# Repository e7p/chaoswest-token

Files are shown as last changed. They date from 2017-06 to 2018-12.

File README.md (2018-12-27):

## Welcome

This is the official documentation of the Chaos-West Token which is given to anyone on the SHA2017 camp and also on the 35C3 who supports us with a reasonable donation for us (mainly to be able to split-up costs we all belonging to Chaos-West share on the event). If you really want to have one of these wonderful and token kits, just come to our Chaos-West info desk on the event and support us with a recommended donation. In case there are some left-overs after the event, it should be somehow possible to receive these if you still want to get a token after the event. The easiest would probably be to write an e-mail to cwtkn@devtal.de which should address the makers of this token. As this is a project released to the public domain, consolidating the thought of open hardware and free software, you can also produce the board by yourself (or wire up the rather simple circuit on a breadboard), but getting it from us really supports the collective activities of Chaos-West, just consider that.

## Quick Start

On 35C3: Please come to me for help flashing!

Elsewise: type `make usbflash` to flash the token.

Attention: When powering the badge it will take about 6 seconds to boot, before anything will be shown (because of the USB firmware upgrade option).

## Package Contents

The token package should consist out of the following components. If something is missing, ask at the Chaos-West main tent for token support.

1. One Printed Circuit Board (PCB)
2. One Coin Cell Holder
3. One Effect-LED (probably you can choose between different ones)
4. One Power Switch
5. Non-Rechargable CR2032 Coin Cell (3 V)
6. Printed Getting Started Guide

If you want to extend your token with additional parts, you can buy all of the neccessary parts afterwards, refer to the part list below for order numbers given as a reference.
You could also ask me for the full version and I could support you with that, as I may have some left-overs from the SHA2017.

## Getting Started

**Warning**: There is no reverse-polarity protection, so be cautionous to insert the battery in the correct direction, the plus-sign of the battery always facing towards you when looking at the side of the PCB with the coin cell holder! If the battery is inserted in the wrong way, it probably will damage other parts of the circuit including the Front LED.

You should have received your token with an [quick start guide](docs/infocard_revb.pdf). Follow the steps and you will get a basic functioning token which blinks when a coin cell is inserted and the switch is slide to the “On”-position. The steps of the printed getting started guide are noted here:

1. Solder the switch.
2. Solder the Coin-Cell holder. The slot should face the top.
3. Solder the Effect LED, mind the polarity (marked “+”) matches with your LED.
4. Insert the battery, switch on, and enjoy the blinking / fading LED effects.

That's it basically. If you want more, read on, as there are many more possibilities in this little token PCB.

## Features

* Front LED lighting up
* Coin Cell Holder for CR2032 (standard) or LIR2032 (Li-Ion) Type Batteries
* Power Switch
* 8-bit Microcontroller with ISP-interface
* (Actually Precise) Temperature Sensor
* Up to Five WS2813 LEDs (and pads for extending to other WS281x-stripes, supporting the new WS2813 ones aswell)
* USB
* Li-Ion Charging Circuit (via USB)
* Microcontroller Firmware In-System-Programmable (ISP) or Directly Via USB

## Partlist

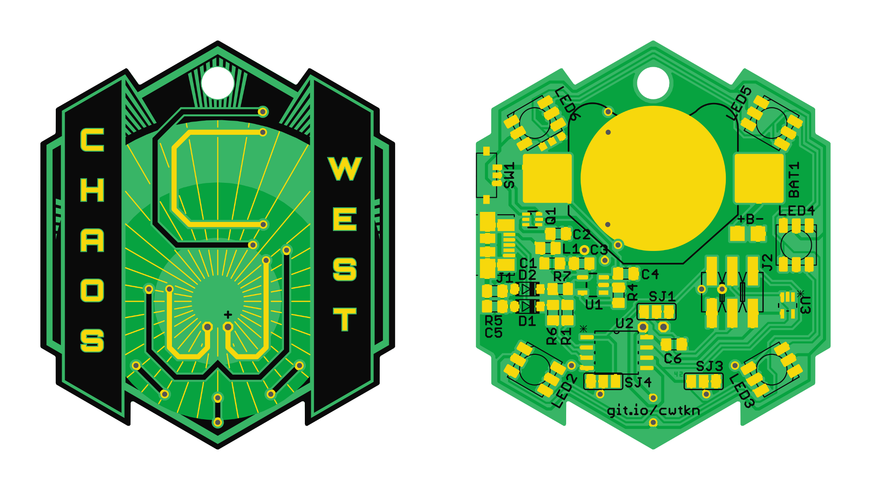
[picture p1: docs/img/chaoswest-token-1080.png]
Schematic drawing of the both sides of the PCB


All parts, except from the thru-hole LED on the front are SMD-components, which means that their pins are soldered directly on the exposed pads of the PCB. Some of the components (Diodes, LEDs and ICs) need to be mounted in a specific direction. This direction can be seen on the drawing above. The mount-direction of the six-pin transistor Q1 is not important as the pinout is symmetric. Not all components are essential. Each build step below references the neccessary and optional parts for each step.

Part         | Value           | Description                                           | Farnell
------------ | --------------- | ----------------------------------------------------- | -------
BAT1         | Keystone 3002   | CR2032 / LIR2032 Coin Cell Holder (only use rechargable LIR2032 with Li-Ion Charger, never use CR2032)                     | 1650693
C1,2,5       | 10 nF           | 0805 Ceramic Capacitor (10V)                          | 1759246
C3,4         | 4.7 µF          | 0805 Ceramic Capacitor (10V)                          | 1759427
C6           | 100 nF          | 0805 Ceramic Capacitor (10V)                          | 9406387
D1,2         | 3.6 V Zener     | SOD-123 Zener Diode                                   | 2069437
J1           | Molex 47346     | Female Micro-USB Jack                                 | 1568026
J2           | 2,54mm header   | 6-pin ISP Header (2x3 pins)                           | 2505049
L1           | 33 Ohm @ 10MHz  | 0805 Ferrite Bead                                     | 1800367
LED1         | Standard        | Various different LEDs<sup>1</sup>                    | 1581189
LED2,3,4,5,6 | WS2813          | RGB-LED with integrated controller                    | -<sup>2</sup>
Q1           | Si1967DH        | SOT-363 Dual P-Channel MOSFET                         | 2335282
R1,6         | 68 Ohm          | 0805 Chip Resistor                                    | 2447707
R4           | 47 kOhm         | 0805 Chip Resistor                                    | 2447664
R5           | 1 MOhm          | 0805 Chip Resistor                                    | 2447596
R7           | 2.2 kOhm        | 0805 Chip Resistor                                    | 2447623
SJ1,3,4      | -               | either short or current limiting resistor<sup>1</sup> | 2447606
SW1          | AYZ0102AGRLC    | SPDT Switch                                           | 2319971<sup>3</sup>
U1           | MCP7383xT-2ACI  | Single-Cell Li-Ion Charging IC                        | 1332158
U2           | ATtiny85-20SU   | SOIC-8 20 MHz AVR Microcontroller                     | 1972176
U3           | MCP9700AT-E/LT  | SC70-5 Temperature Sensor                             | 1332165

<sup>1</sup>: For LED1 many options are available (including Effect-LEDs and standard one- and multicolor LEDs). This also results in different possible usages of the solder-jumpers SJ1,3 and 4. Check the specific section "Front LED" for this.<br />
<sup>2</sup>: The WS2813 LEDs are not yet commonly available. Check for example TME, eBay or AliExpress for these.
<sup>3</sup>: Revision B got a different switch, so the switch in Revision A was ALPS SSAJ120100 which has Farnell number 2056803.

### Testpads

There are a few additional pads which are meant for additional features not included in the default version of this board. See this short reference as the full description of these and refer to the schematic for reference.

Pads      | Description
--------- | -----------
+B-       | On these pads an Lithium-Polymer single cell could be soldered when not using the coin-cell holder. When not using the Li-Ion Charger circuit, these pads can generally be used to supply about 2.4 to 5 volts to the board.
DO,BO,GND | These are located beneath LED6 (DO outermost, following BO, and GND most to the center of the board) and are for chaining additional WS281x-LEDs to the board. BO is only used for WS2813 whereas DO is the standard WS281x-signal output of the last on-board WS2813-LED LED6.

## Build

The full feature-set of the token can be only achieved when soldering extensions and doing very small modifications to the board. This section gives an overview about which modification “checkpoints” can be reached at which each more and more features are achieved, yet ranging from very simple one-part soldering jobs up to own modifications on a microcontroller firmware involving even USB-development.

View of the different groups of component for each step

### Essentials

Components: BAT1, LED1, SW1

When receiving your token, you will find an Effect LED, a switch, and coin cell holder within your kit. This is enough to start with a very simple circuit: The LED is connected directly to the battery terminals and thus is lit whenever a coin cell with a sufficiently high voltage is inserted and the switch is turned on.

Any other part of the circuit (like the microcontroller, or a current limiting resistor for the LED) is by default bypassed, which means that some of the pads of the LED solder jumper (SJ1) and the switch (SW1) are interconnected with small traces. If for example the effect LED is exchanged with a standard non-blinking LED, a current limiting resistor is necessary, which means that a small trace between two of the pads of SJ1 must be cut and a sufficiently large-valued (e.g. 220 ohms) resistor soldered there instead.

### Other LED

Components: SJ3, SJ4

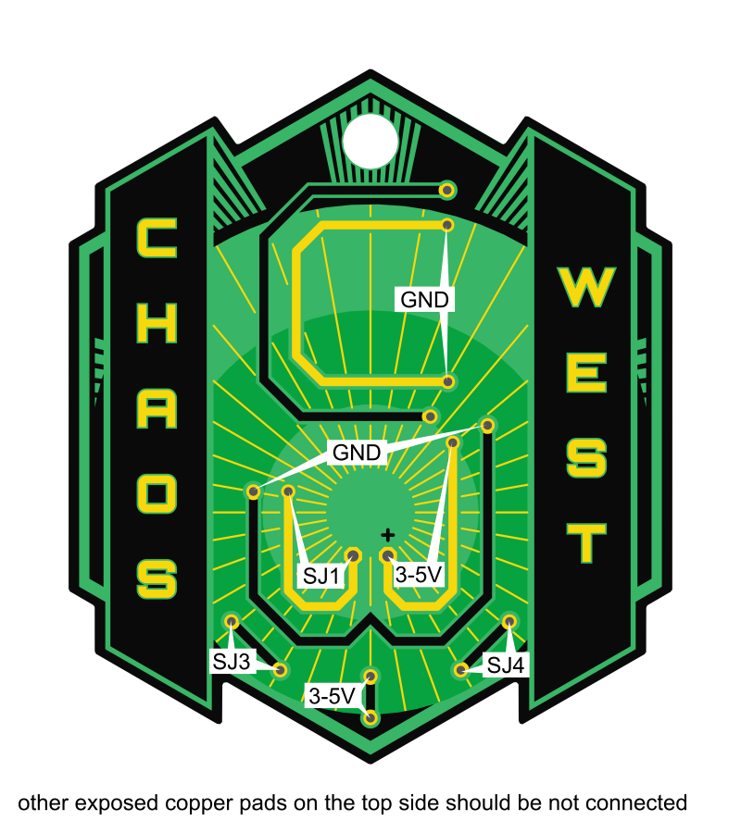
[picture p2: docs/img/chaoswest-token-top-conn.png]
Exposed signals on the top-side of the PCB


Similar to the main LED (see above), SJ3 and SJ4 allow at least two more arbitrary LEDs to be soldered on the front side of the board. Usually the SJ-pads will be connected to the cathode of the LEDs except for one case: common cathode multi-color LEDs. But this will be topic of a following section. This means, that the anode of the LEDs should be connected to one of the 3-5 V (VCC) pads and the cathode (preferably) to the middle pads of SJ1,3,4 which are with vias in the logo brought to the front side. The same as for the main LED has taken into account here: If the LED is blinking, it usually doesn't require a current limiting resistor. If it is a standard (maybe multicolor or RGB) LED, then a current limiting resistor is strictly required, missing resistors causing damage to the LED.

### Li-Ion Charger and USB Jack

TODO

The power switch is also by default bypassed for the charging functionality, which makes it necessary to cut traces connected with the switches pads. The switch has three pins of which two are by default connected together. For using the Li-Ion Charging circuit, you need to cut the trace for this step. The trace to be cut is marked with a very small black box of silk screen.

Never use the charging circuit for normal CR2032 coin cells. If you solder, you can only use single Li-Ion Cells in the coin cell holder or on the exposed battery pads (for larger battery packs).

R4: for greater Li-Ion Cells can be other (330mAh: 4k works), charging-rate originally set for smaller LIR2032 (about 20mAh). Refer to the MCP7383 datasheet for more details on this “Program” resistor.

R7: This from the schematic is connected between USB-DM and +5V, but it must be connected between USB-DM and VCC. Otherwise it _won't boot_ when a bootloader is flashed on the Microcontroller and run from the battery. So it is neccessary to solder only the USB-DM pad of R7 to the resistor and leave the other side of the resistor in the air and then solder some copper wire between this and a VCC pad.

### Microcontroller and ISP Port

TODO

When using the bootloader, keep in mind that R7 needs to be bodge-wired (see topic “Li-Ion Charger and USB Jack”.

### Temperature Sensor

The MCP9700AT-E/LT temperature sensor has an range of -40°C to 125°C with a maximum tolerance of ±2°C tolerance. If it is calibrated at 25°C, a tolerance of ±1°C can be achieved. It is connected to pin PB2 and can be read out using the Analog/Digital-Converter channel 1 (ADC1).

### WS2813 LEDs

There are footprints on the board for up to five WS2813-type LEDs. These integrate a full-color RGB-PWM generator and 24-bit shift register logic which allows to chain this kind of LEDs to a long chain which is controlled by a single pin.

## Front LED

### Options
* Single Color (red, amber, yellow, green, blue, pink, white, UV, IR) Standard LED
* Common-Anode RGB-LED
* Common-Cathode RGB-LED
* Disco Effect LED
* Slow-Fading Effect LED
* Blinking LED
* [WS2812 Thru-Hole LED](https://www.adafruit.com/product/1938)
* ... possibly any 10/5/3mm Thru-Hole LED one could think of

In any case, the status of the LED can be controlled by the microcontroller, if it is fitted and the solder jumpers are set correctly.

## USB

The USB jack can be used to charge the Li-Ion battery or to exchange data between an USB-host and the microcontroller on the token. With a special bootloader, it is also possible to flash the microcontroller firmware directly over the USB-port, so there is really nothing more than a standard USB-port on a PC needed to start developing own programs and flashing them to the token. An ISP-type-programmer is then only necessary for programming the bootloader into the microcontroller for the very first time.

### Bootloader
[micronucleus](https://github.com/micronucleus/micronucleus)

To write the Bootloader, connect via ISP port (or SO-8 clamp directly on the AtTiny).

_Important_: It is neccessary to flash without the temperature sensor, as it would override the clock pin of the ISP process.

Flash the Bootloader (micronucleus default build for ATTiny85 or Digispark) with the following commands:

1. `cd firmware`
2. `make flash fuse` (only continue if successfully and connectable via USB; DigiSpark Driver)
3. `make disablereset` (this _disables_ the Reset functionality and won't allow you to flash the ATTiny85 again via ISP. After this fusing it is only possible via HVSP to rescue a wrongly flashed ATTiny85).

When using the bootloader, keep in mind that R7 needs to be bodge-wired (see topic “Li-Ion Charger and USB Jack”.

## Firmware

`make usbflash` should be enough to flash to a token with installed micronucleus bootloader.

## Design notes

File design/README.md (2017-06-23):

This design archive shows the workflow of how the logo came from its svg original into eagle.

1. First a complete redraw (including symmetry achieved by dependencies and measurings) was done in Inventor.
2. Then the single sketches were exported as DXF and further overworked using QCAD
3. Afterwards the awesome [import-dxf v1.6](https://github.com/erikwilson/import-dxf/) tool was used, to get the DXF files into eagle.
4. Sometimes these need to be slightly overworked. But more problematic is, that we mostly want to import the lines, curves and polylines as a polygon.
   So I decided to write a rather simple script ([polysignals.py](03_polysignals/polysignals.py)) which can convert closed eagle figures (hereby called signals, as this is done automatically when importing DXF files into copper layers) out of wires into respective polygons, keeping any curves correctly and allowing to replace individual wire coordinates with a straightforward yet simple syntax, which is also able to append additional coordinates. With that, it is even possible to put cutouts into the very same polygon.
5. The resulting XML polygons were than inserted into the eagle BRD file, replacing the wires generated during the DXF import.

I think this procedure is quite good for getting even complex vector logos into eagle, eventhough it is a bit annoying. Still, please note that eagle is a fantastic tool for creating multi-layer printed circuit board and is not made for the purpose to create great looking PCB art. But with their simple XML format eagle is very hacker approved in my opinion, without the need to bother with writing special ULPs or SCRipts.

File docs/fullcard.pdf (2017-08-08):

# Full Version

Features:
- Microcontroller
- Temperature Sensor
- USB (charging & data)
- LIR2032 rechargable Coin Cell
- RGB LED
- Support for WS2813 LEDs
1. upload Firmware (git.io/cwtkn)
2. check for updates on github

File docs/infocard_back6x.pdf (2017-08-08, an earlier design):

1. Solder the Coin-Cell holder The slot should face the top
2. Solder the Effect LED, mind the polarity (marked “+”)
matches with your LED
3. (Optionally) solder the switch
Cut the shown trace first,
then solder the switch!
4. Insert the battery, (eventually switch on,)
and enjoy the blinking / fading LED effects

Quick Start Guide

Please read also the safety advices on the back

# flat edgeSW¹

cut here

1. Solder the Coin-Cell holder
The slot should face the top
2. Solder the Effect LED, mind the polarity (marked “+”)
matches with your LED
3. (Optionally) solder the switch
Cut the shown trace first,
then solder the switch!
4. Insert the battery, (eventually switch on,)
and enjoy the blinking / fading LED effects

Quick Start Guide

Please read also the safety advices on the back

# flat edgeSW¹

cut here

1. Solder the Coin-Cell holder The slot should face the top
2. Solder the Effect LED, mind the polarity (marked “+”)
matches with your LED
3. (Optionally) solder the switch
Cut the shown trace first,
then solder the switch!
4. Insert the battery, (eventually switch on,)
and enjoy the blinking / fading LED effects

Quick Start Guide

Please read also the safety advices on the back

# flat edgeSW¹

cut here

1. Solder the Coin-Cell holder
The slot should face the top
2. Solder the Effect LED, mind the polarity (marked “+”)
matches with your LED
3. (Optionally) solder the switch
Cut the shown trace first,
then solder the switch!
4. Insert the battery, (eventually switch on,)
and enjoy the blinking / fading LED effects

Quick Start Guide

Please read also the safety advices on the back

# flat edgeSW¹

cut here

1. Solder the Coin-Cell holder The slot should face the top
2. Solder the Effect LED, mind the polarity (marked “+”)
matches with your LED
3. (Optionally) solder the switch
Cut the shown trace first,
then solder the switch!
4. Insert the battery, (eventually switch on,)
and enjoy the blinking / fading LED effects

Quick Start Guide

Please read also the safety advices on the back

# flat edgeSW¹

cut here

1. Solder the Coin-Cell holder
The slot should face the top
2. Solder the Effect LED, mind the polarity (marked “+”)
matches with your LED
3. (Optionally) solder the switch
Cut the shown trace first,
then solder the switch!
4. Insert the battery, (eventually switch on,)
and enjoy the blinking / fading LED effects

Quick Start Guide

Please read also the safety advices on the back

# flat edgeSW¹

cut here

1. Solder the Coin-Cell holder The slot should face the top
2. Solder the Effect LED, mind the polarity (marked “+”)
matches with your LED
3. (Optionally) solder the switch
Cut the shown trace first,
then solder the switch!
4. Insert the battery, (eventually switch on,)
and enjoy the blinking / fading LED effects

Quick Start Guide

Please read also the safety advices on the back

# flat edgeSW¹

cut here

1. Solder the Coin-Cell holder
The slot should face the top
2. Solder the Effect LED, mind the polarity (marked “+”)
matches with your LED
3. (Optionally) solder the switch
Cut the shown trace first,
then solder the switch!
4. Insert the battery, (eventually switch on,)
and enjoy the blinking / fading LED effects

Quick Start Guide

Please read also the safety advices on the back

# flat edgeSW¹

cut here

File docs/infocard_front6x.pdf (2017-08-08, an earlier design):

Welcome This is the Chaos-West Token of the camp For more Information, visit https://git.io/cwtkn Safety Advices The polarity of the battery is important! “+” of the holder must contact “+” of battery Do not have the CR2032 coin cell inserted when the Li-Ion Charging IC is populated and USB is used. Only use LIR2032 or other single Li-Ion cells (3.6 V) for charging Flip this card for a quick start guide | Welcome This is the Chaos-West Token of the camp For more Information, visit https://git.io/cwtkn Safety Advices The polarity of the battery is important! “+” of the holder must contact “+” of battery Do not have the CR2032 coin cell inserted when the Li-Ion Charging IC is populated and USB is used. Only use LIR2032 or other single Li-Ion cells (3.6 V) for charging Flip this card for a quick start guide
Welcome This is the Chaos-West Token of the camp For more Information, visit https://git.io/cwtkn Safety Advices The polarity of the battery is important! “+” of the holder must contact “+” of battery Do not have the CR2032 coin cell inserted when the Li-Ion Charging IC is populated and USB is used. Only use LIR2032 or other single Li-Ion cells (3.6 V) for charging Flip this card for a quick start guide | Welcome This is the Chaos-West Token of the camp For more Information, visit https://git.io/cwtkn Safety Advices The polarity of the battery is important! “+” of the holder must contact “+” of battery Do not have the CR2032 coin cell inserted when the Li-Ion Charging IC is populated and USB is used. Only use LIR2032 or other single Li-Ion cells (3.6 V) for charging Flip this card for a quick start guide
Welcome This is the Chaos-West Token of the camp For more Information, visit https://git.io/cwtkn Safety Advices The polarity of the battery is important! “+” of the holder must contact “+” of battery Do not have the CR2032 coin cell inserted when the Li-Ion Charging IC is populated and USB is used. Only use LIR2032 or other single Li-Ion cells (3.6 V) for charging Flip this card for a quick start guide | Welcome This is the Chaos-West Token of the camp For more Information, visit https://git.io/cwtkn Safety Advices The polarity of the battery is important! “+” of the holder must contact “+” of battery Do not have the CR2032 coin cell inserted when the Li-Ion Charging IC is populated and USB is used. Only use LIR2032 or other single Li-Ion cells (3.6 V) for charging Flip this card for a quick start guide
Welcome This is the Chaos-West Token of the camp For more Information, visit https://git.io/cwtkn Safety Advices The polarity of the battery is important! “+” of the holder must contact “+” of battery Do not have the CR2032 coin cell inserted when the Li-Ion Charging IC is populated and USB is used. Only use LIR2032 or other single Li-Ion cells (3.6 V) for charging Flip this card for a quick start guide | Welcome This is the Chaos-West Token of the camp For more Information, visit https://git.io/cwtkn Safety Advices The polarity of the battery is important! “+” of the holder must contact “+” of battery Do not have the CR2032 coin cell inserted when the Li-Ion Charging IC is populated and USB is used. Only use LIR2032 or other single Li-Ion cells (3.6 V) for charging Flip this card for a quick start guide

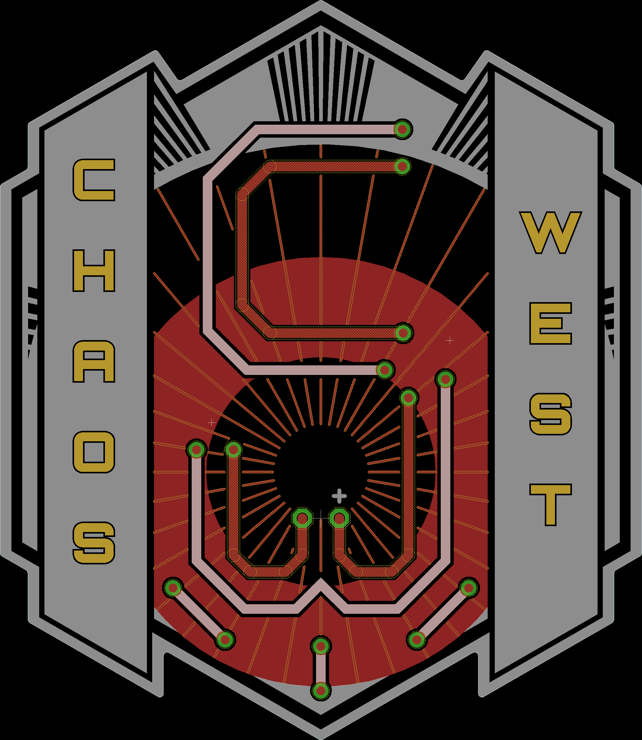
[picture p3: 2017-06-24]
eagle.png

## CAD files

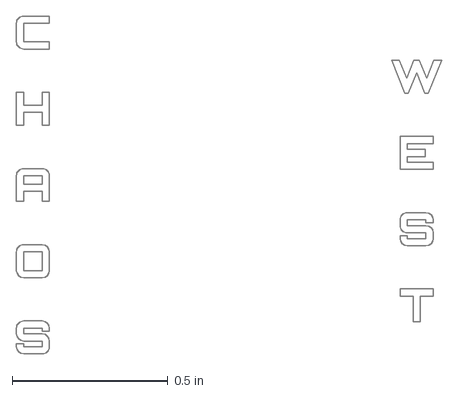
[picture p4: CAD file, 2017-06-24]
design/02_dxf/chaoswest-logo_stop_text2.dxf
1.37 x 1.09 in

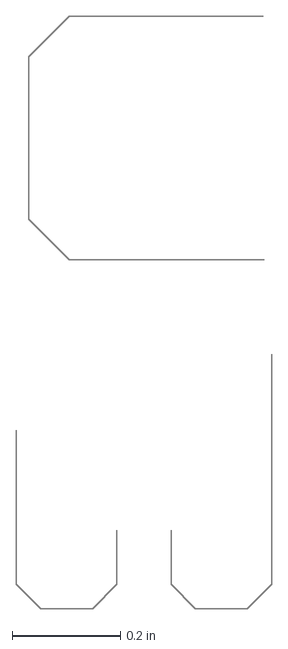
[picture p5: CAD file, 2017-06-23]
design/02_dxf/chaoswest-logo_stop_tracelines_33mil.dxf
0.472 x 1.09 in

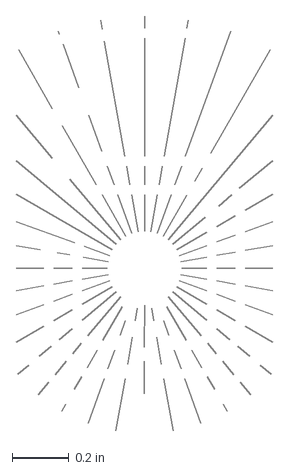
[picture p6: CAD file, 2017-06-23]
design/02_dxf/chaoswest-logo_copper_beams.dxf
0.9 x 1.46 in

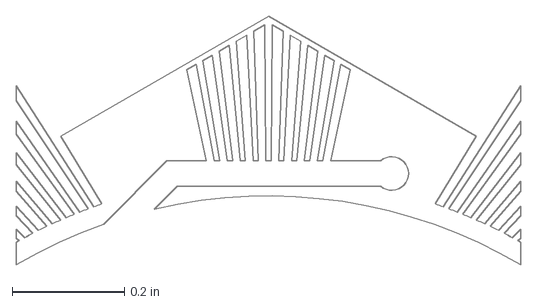
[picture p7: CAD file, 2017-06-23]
design/02_dxf/chaoswest-logo_silk_outer_top2.dxf
0.9 x 0.444 in

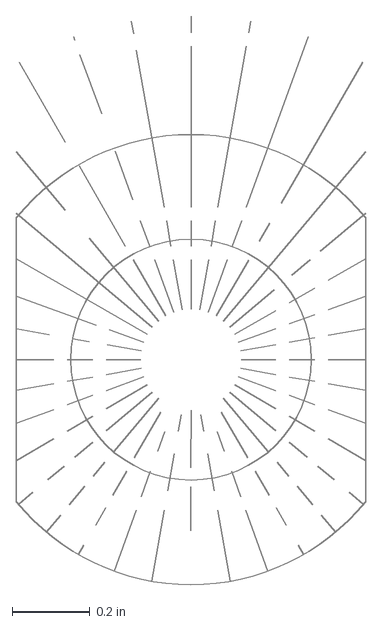
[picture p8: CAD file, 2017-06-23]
design/02_dxf/chaoswest-logo_helper_beams_2.dxf
0.9 x 1.47 in

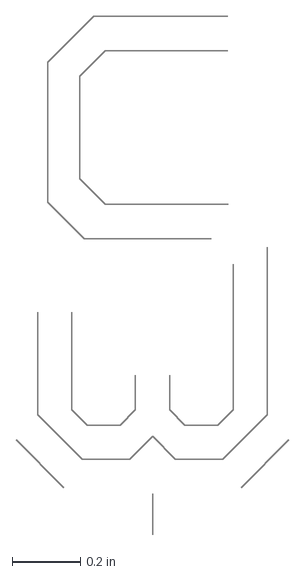
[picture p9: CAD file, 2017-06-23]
design/02_dxf/chaoswest-logo_copper_tracelines_25mil.dxf
0.798 x 1.52 in

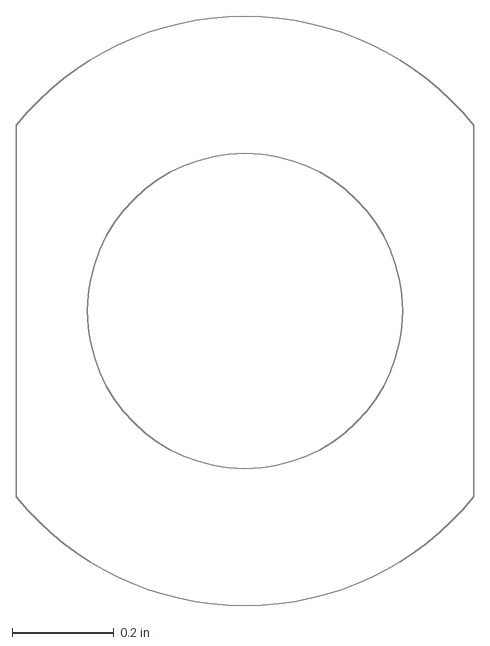
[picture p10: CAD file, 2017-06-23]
design/02_dxf/chaoswest-logo_copper_inner.dxf
0.9 x 1.16 in

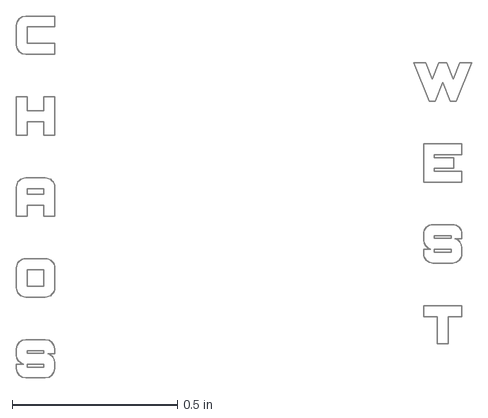
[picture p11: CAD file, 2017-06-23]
design/02_dxf/chaoswest-logo_stop_text.dxf
1.38 x 1.10 in

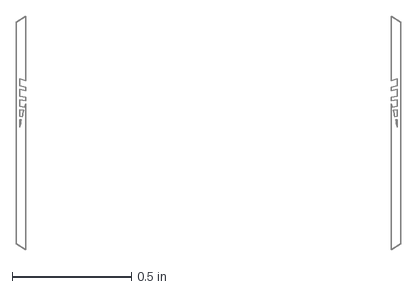
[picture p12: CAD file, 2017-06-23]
design/02_dxf/chaoswest-logo_silk_outer_sides.dxf
1.61 x 0.977 in

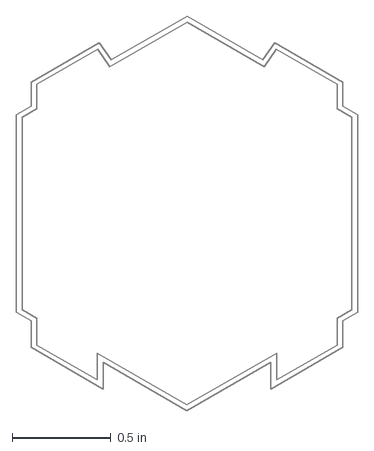
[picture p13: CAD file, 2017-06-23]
design/02_dxf/chaoswest-logo_silk_outer_border.dxf
1.73 x 2.00 in

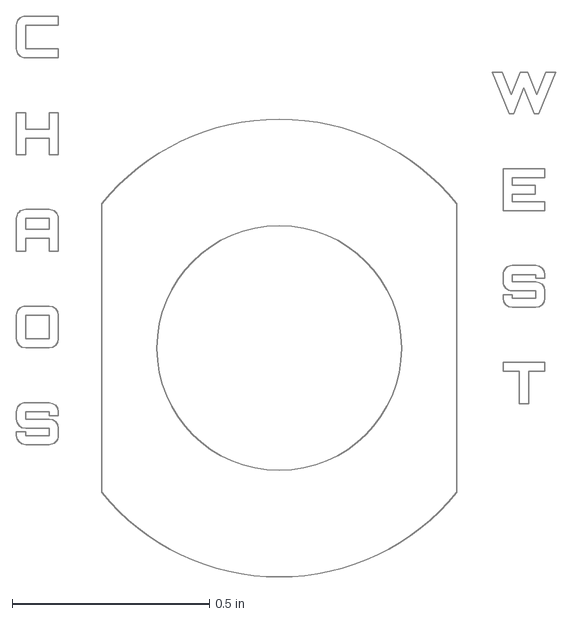
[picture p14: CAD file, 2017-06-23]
design/02_dxf/chaoswest-logo_copper_poly.dxf
1.37 x 1.42 in

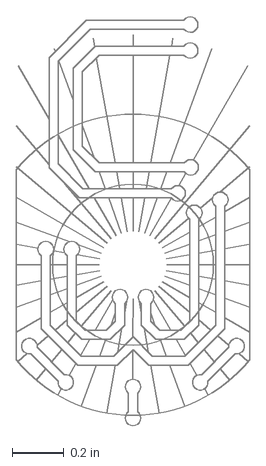
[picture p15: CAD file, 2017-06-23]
design/02_dxf/chaoswest-logo_helper_beams.dxf
0.9 x 1.58 in

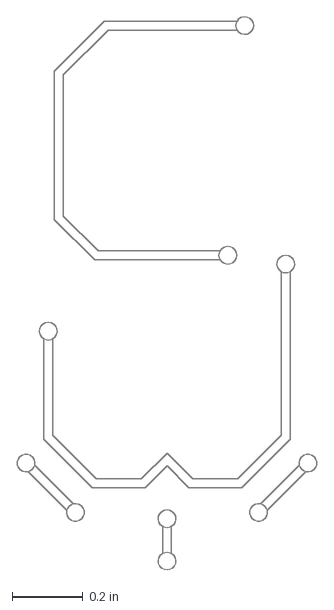
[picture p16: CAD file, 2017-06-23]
design/02_dxf/chaoswest-logo_silk_traces.dxf
0.853 x 1.57 in

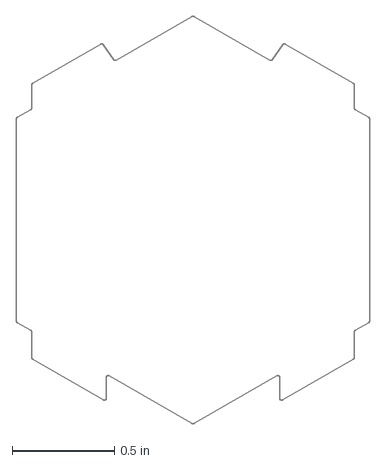
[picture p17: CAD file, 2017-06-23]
design/02_dxf/chaoswest-logo-milling.dxf
1.73 x 2.00 in

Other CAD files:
design/01_inventor/chaoswest-logo_8.ipt
design/01_inventor/chaoswest-logo_9.ipt

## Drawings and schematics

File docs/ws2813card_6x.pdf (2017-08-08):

WS2813 5 LEDs Correct orientation while | WS2813 5 LEDs Correct orientation while

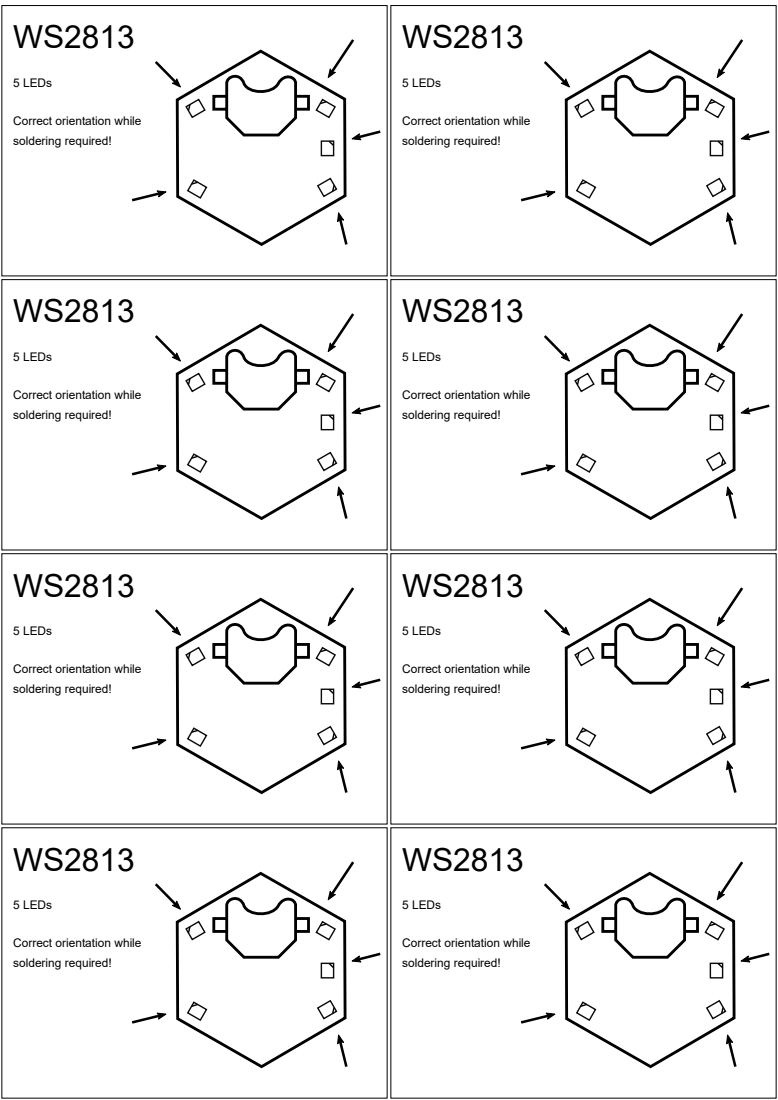
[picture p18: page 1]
soldering required!

WS2813 5 LEDs Correct orientation while | WS2813 5 LEDs Correct orientation while

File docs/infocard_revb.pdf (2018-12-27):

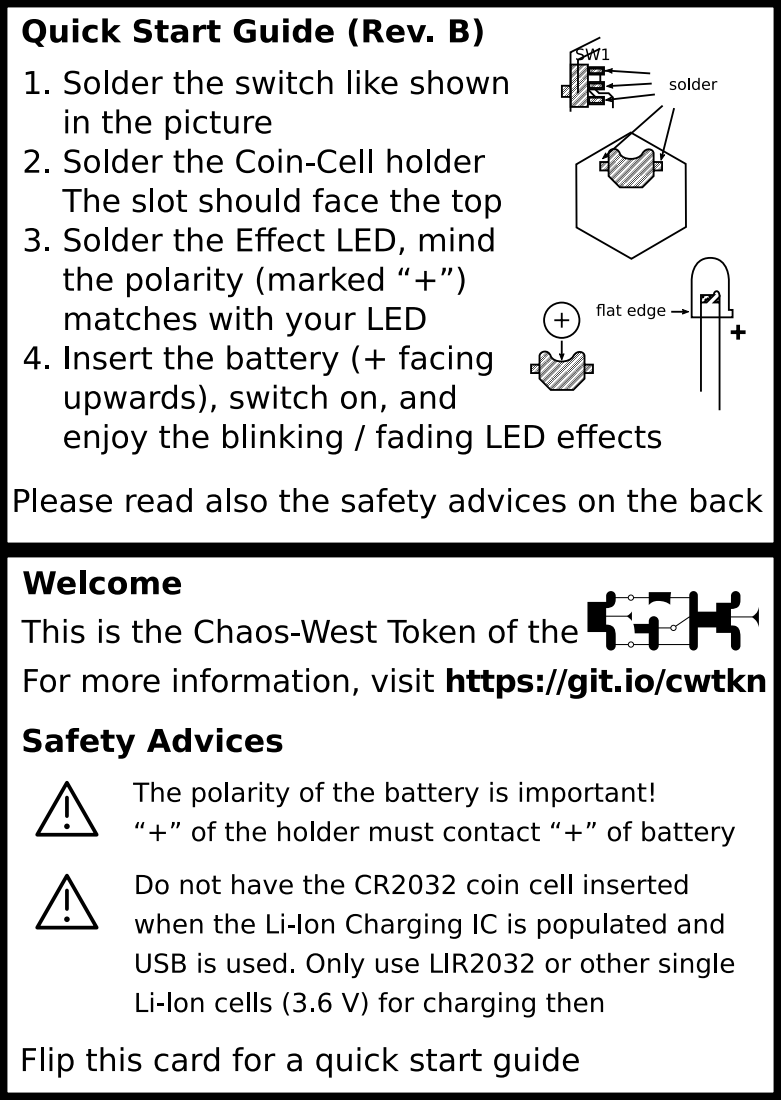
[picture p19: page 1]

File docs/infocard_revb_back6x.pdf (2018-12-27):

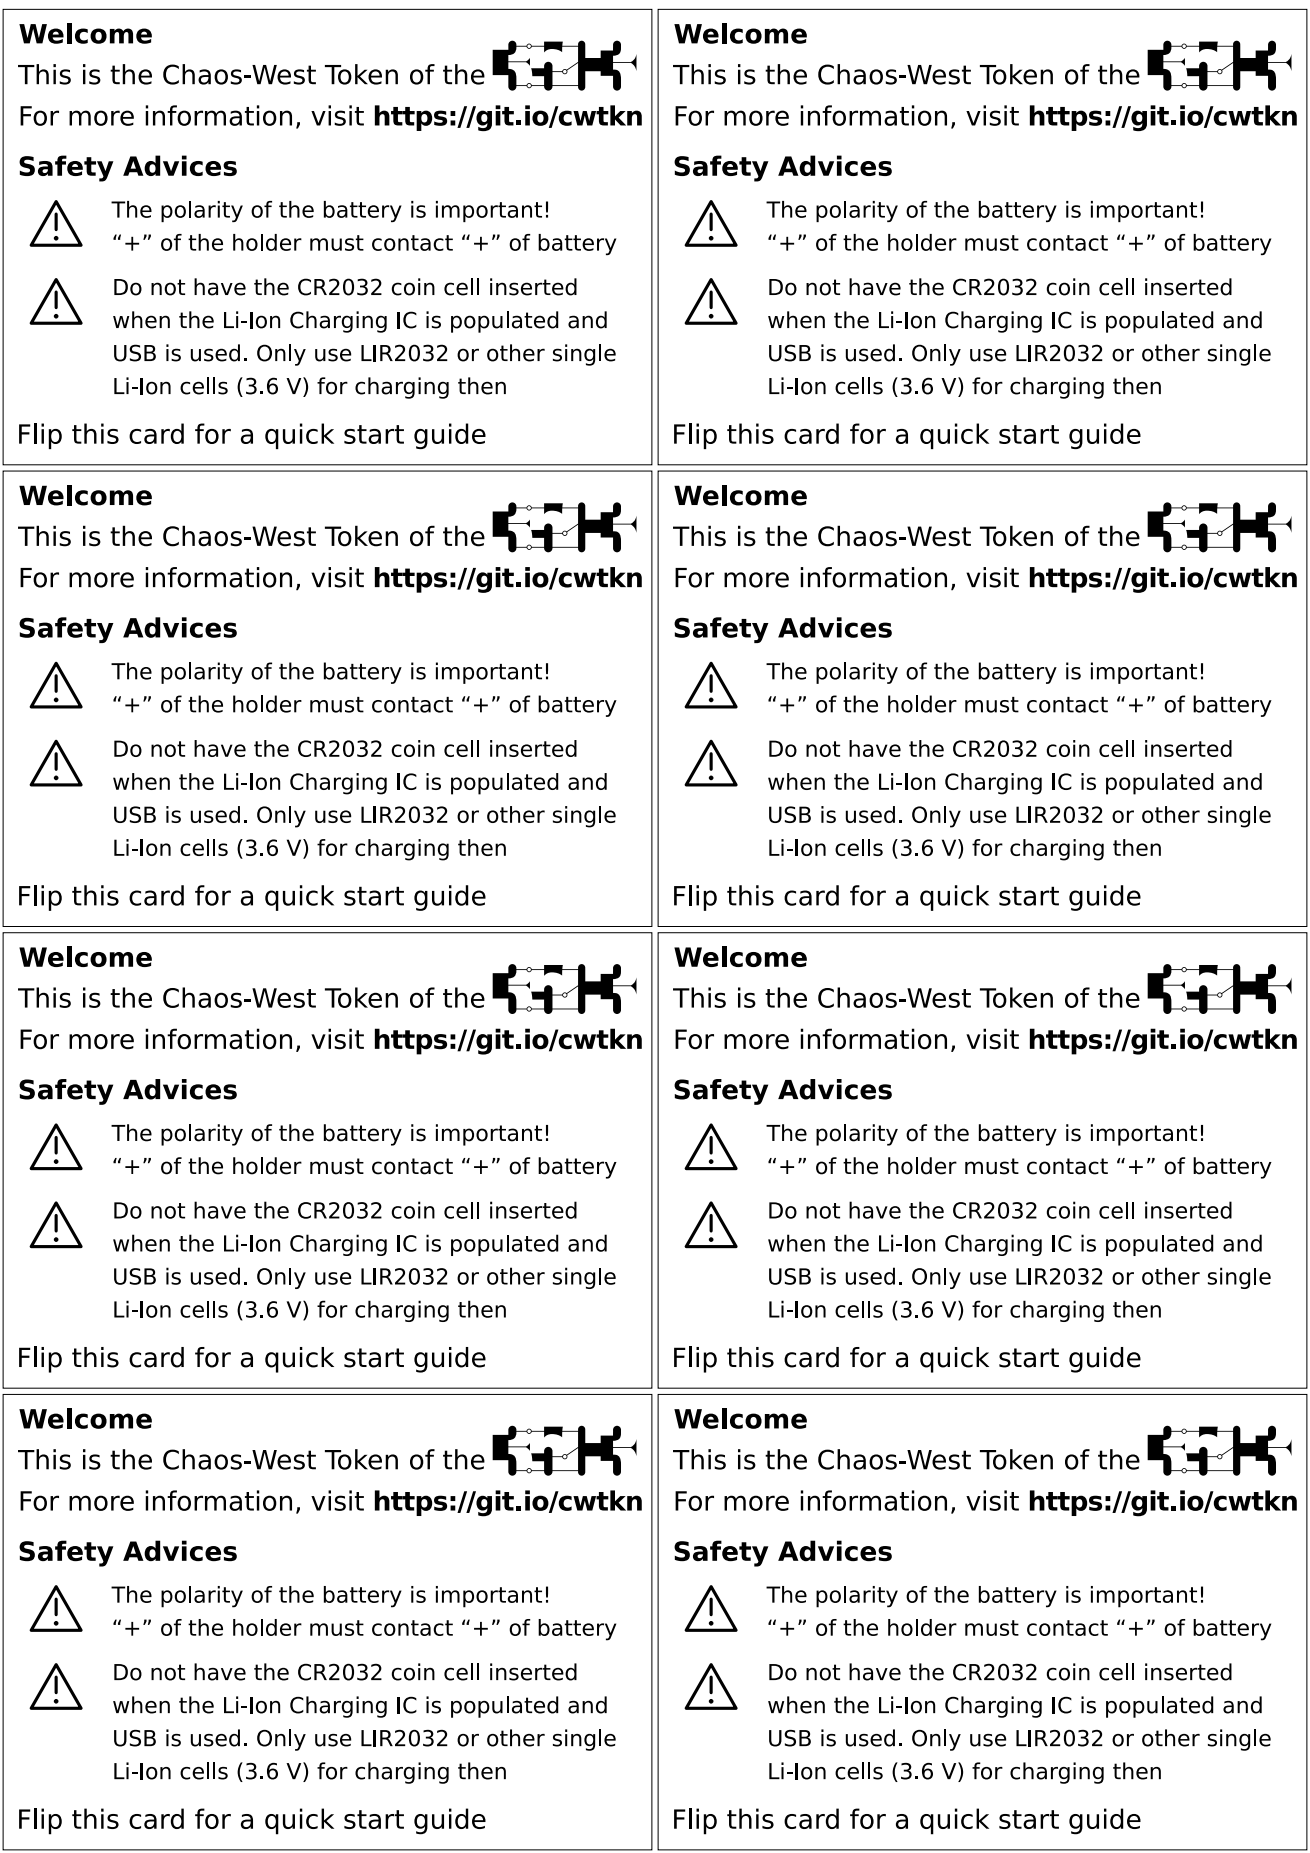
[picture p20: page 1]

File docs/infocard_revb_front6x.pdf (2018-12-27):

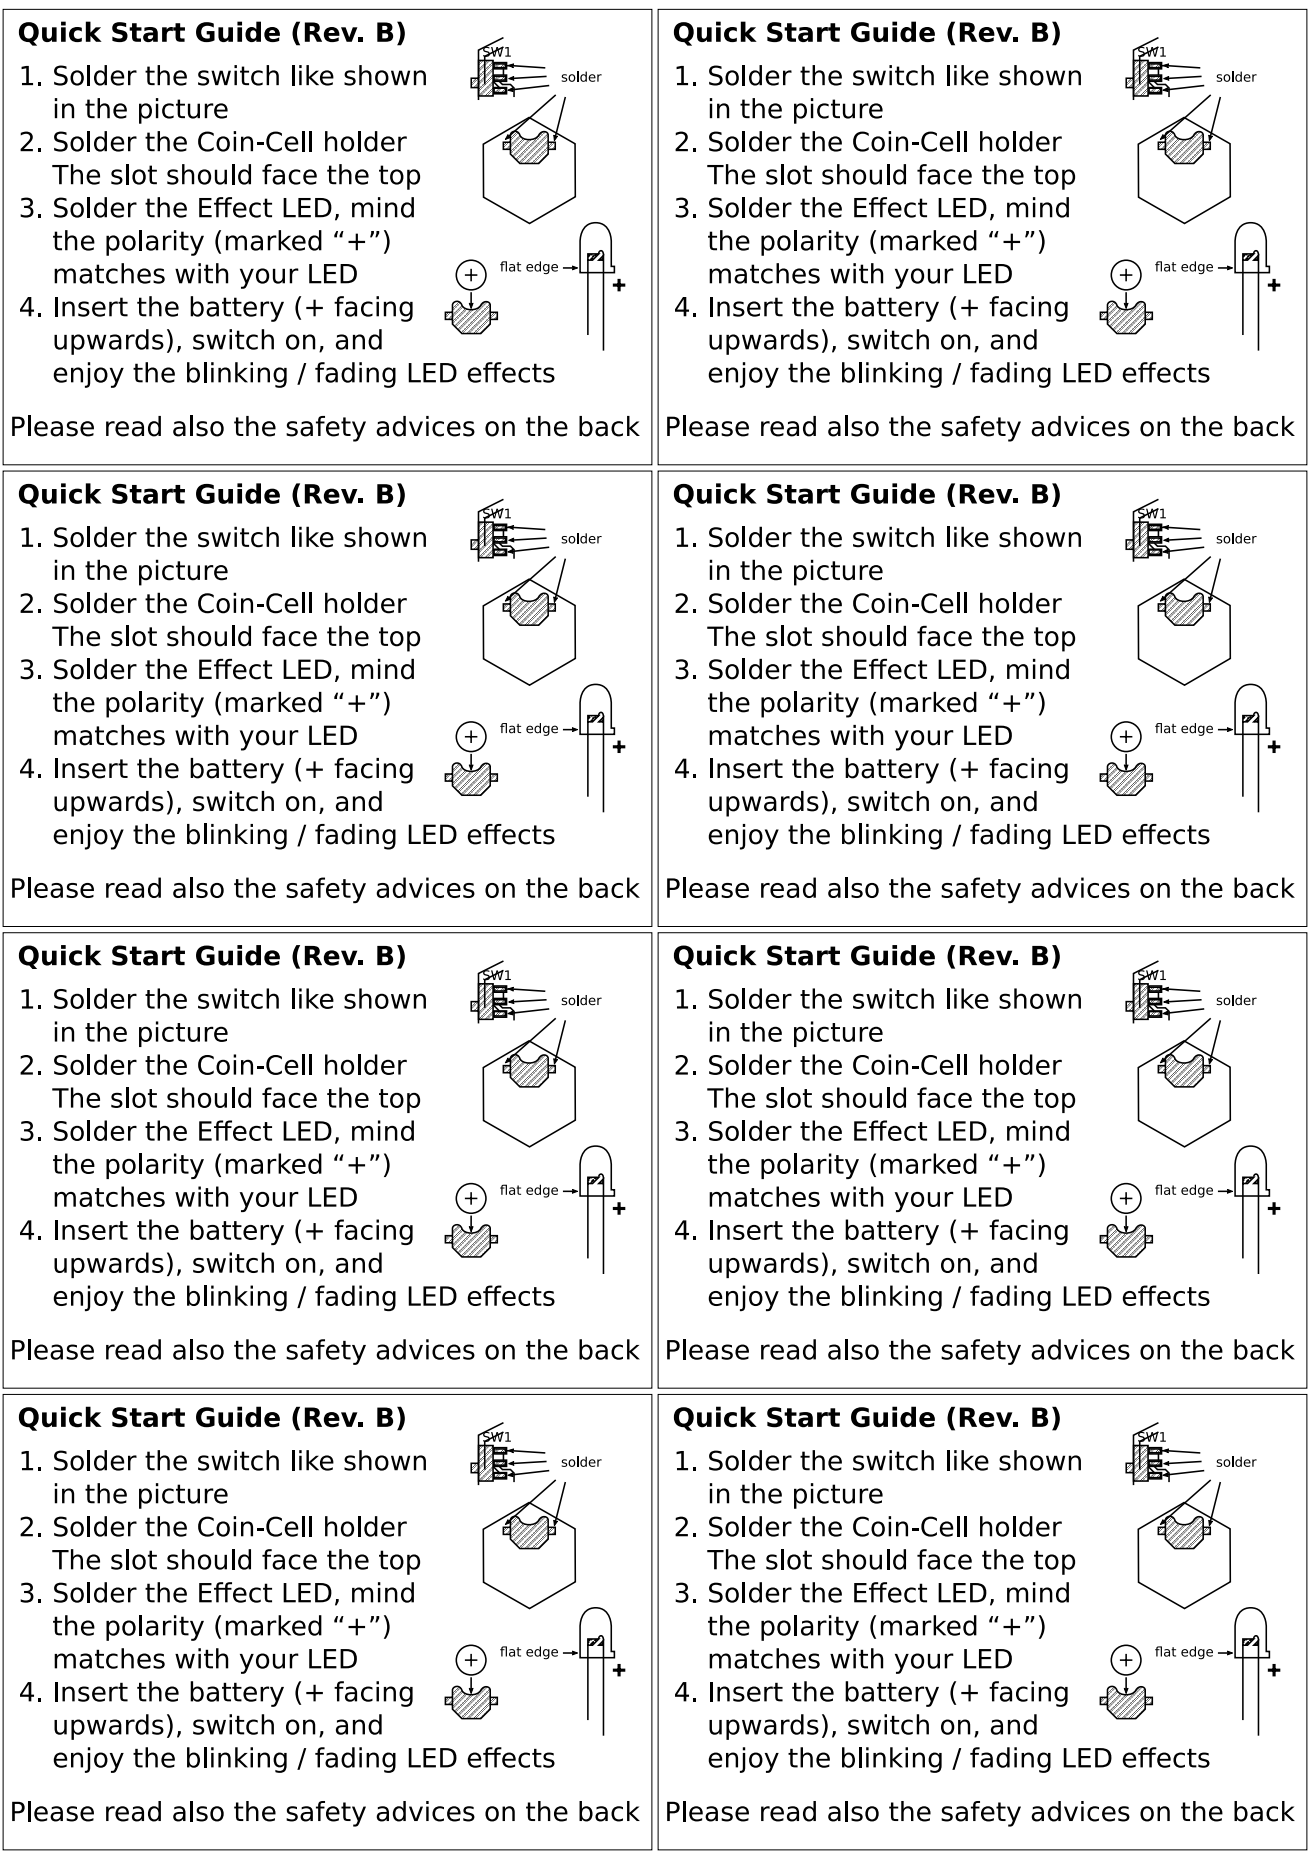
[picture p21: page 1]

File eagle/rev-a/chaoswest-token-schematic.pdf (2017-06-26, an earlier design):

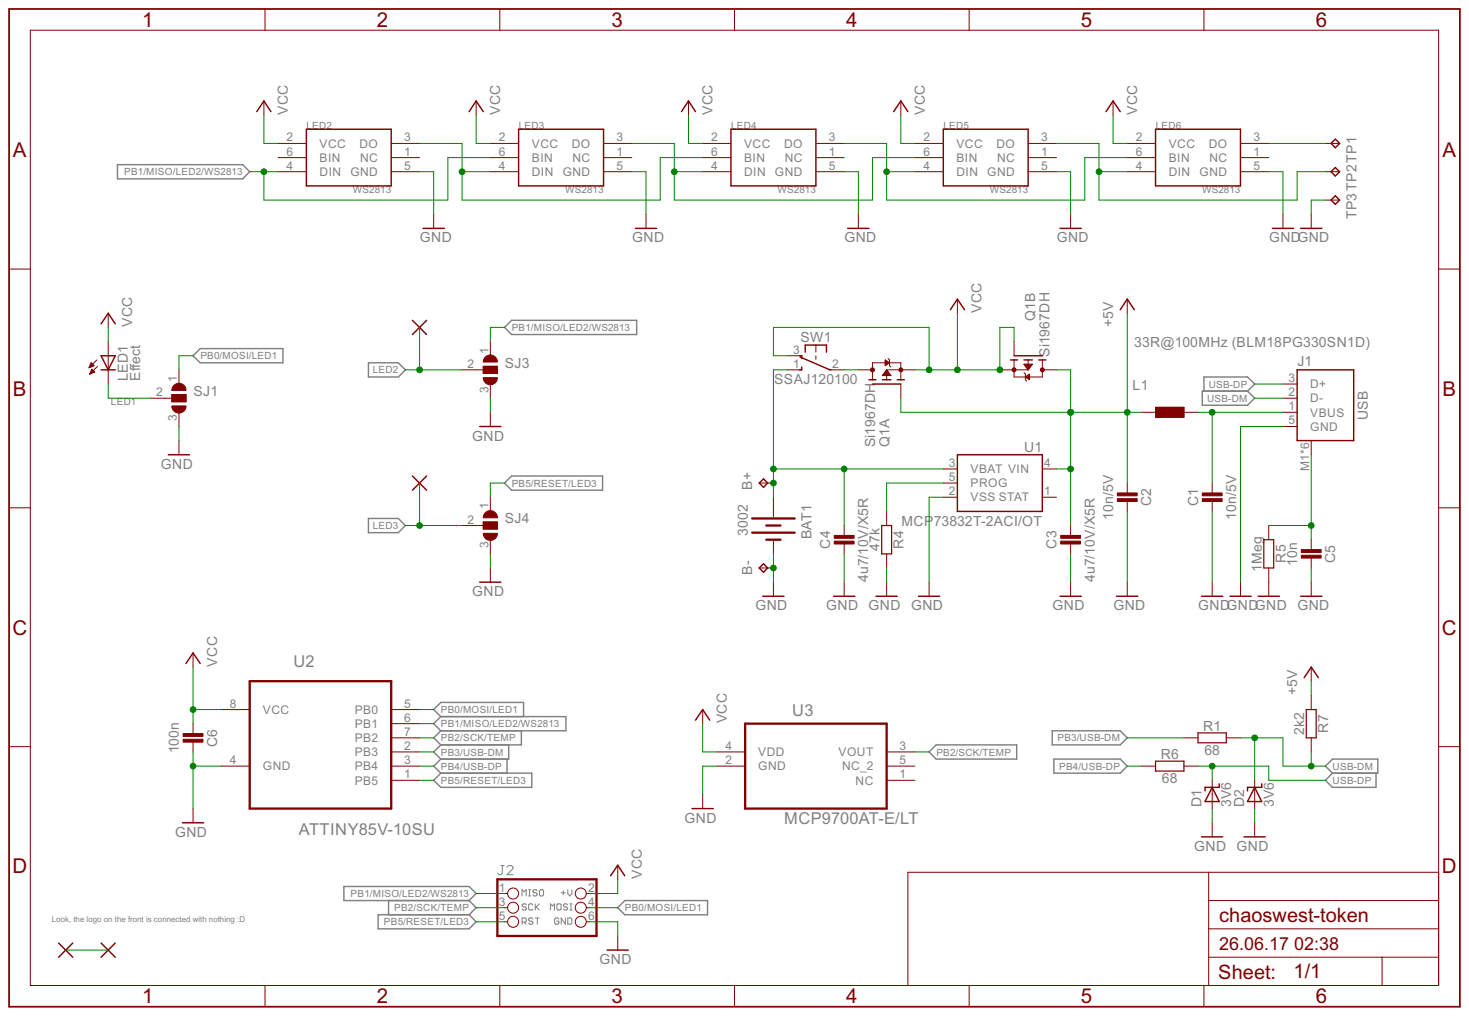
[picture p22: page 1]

Look, the logo on the front is connected with nothing :D

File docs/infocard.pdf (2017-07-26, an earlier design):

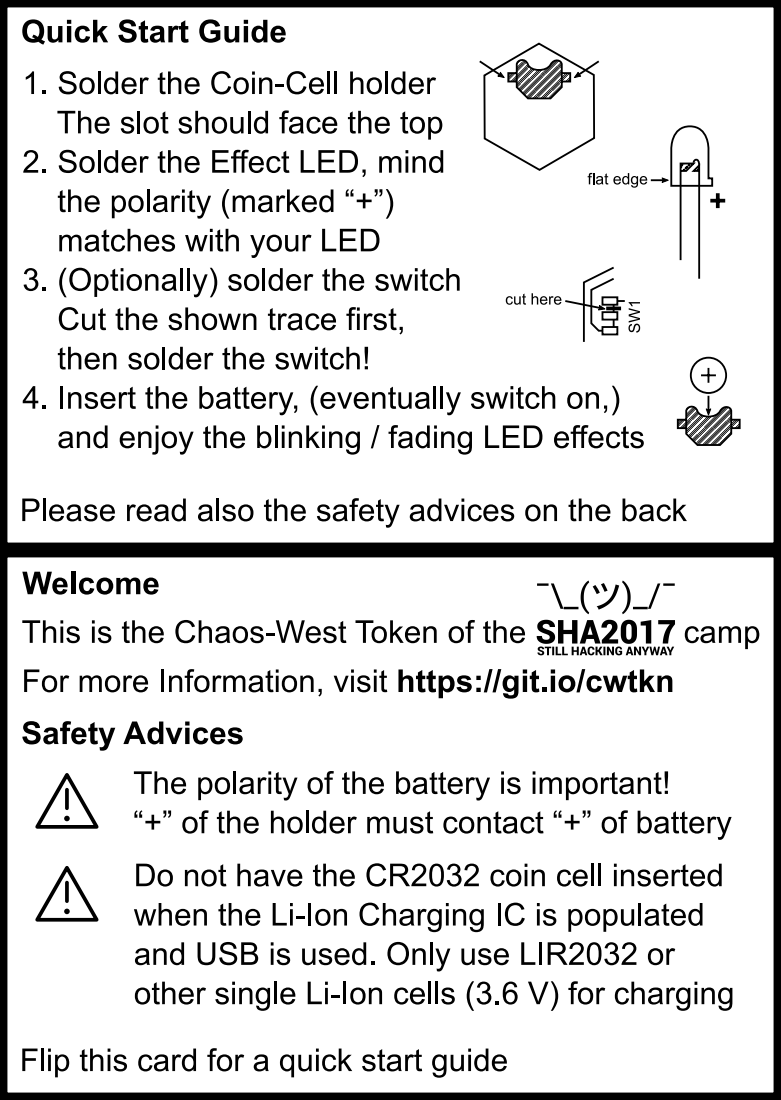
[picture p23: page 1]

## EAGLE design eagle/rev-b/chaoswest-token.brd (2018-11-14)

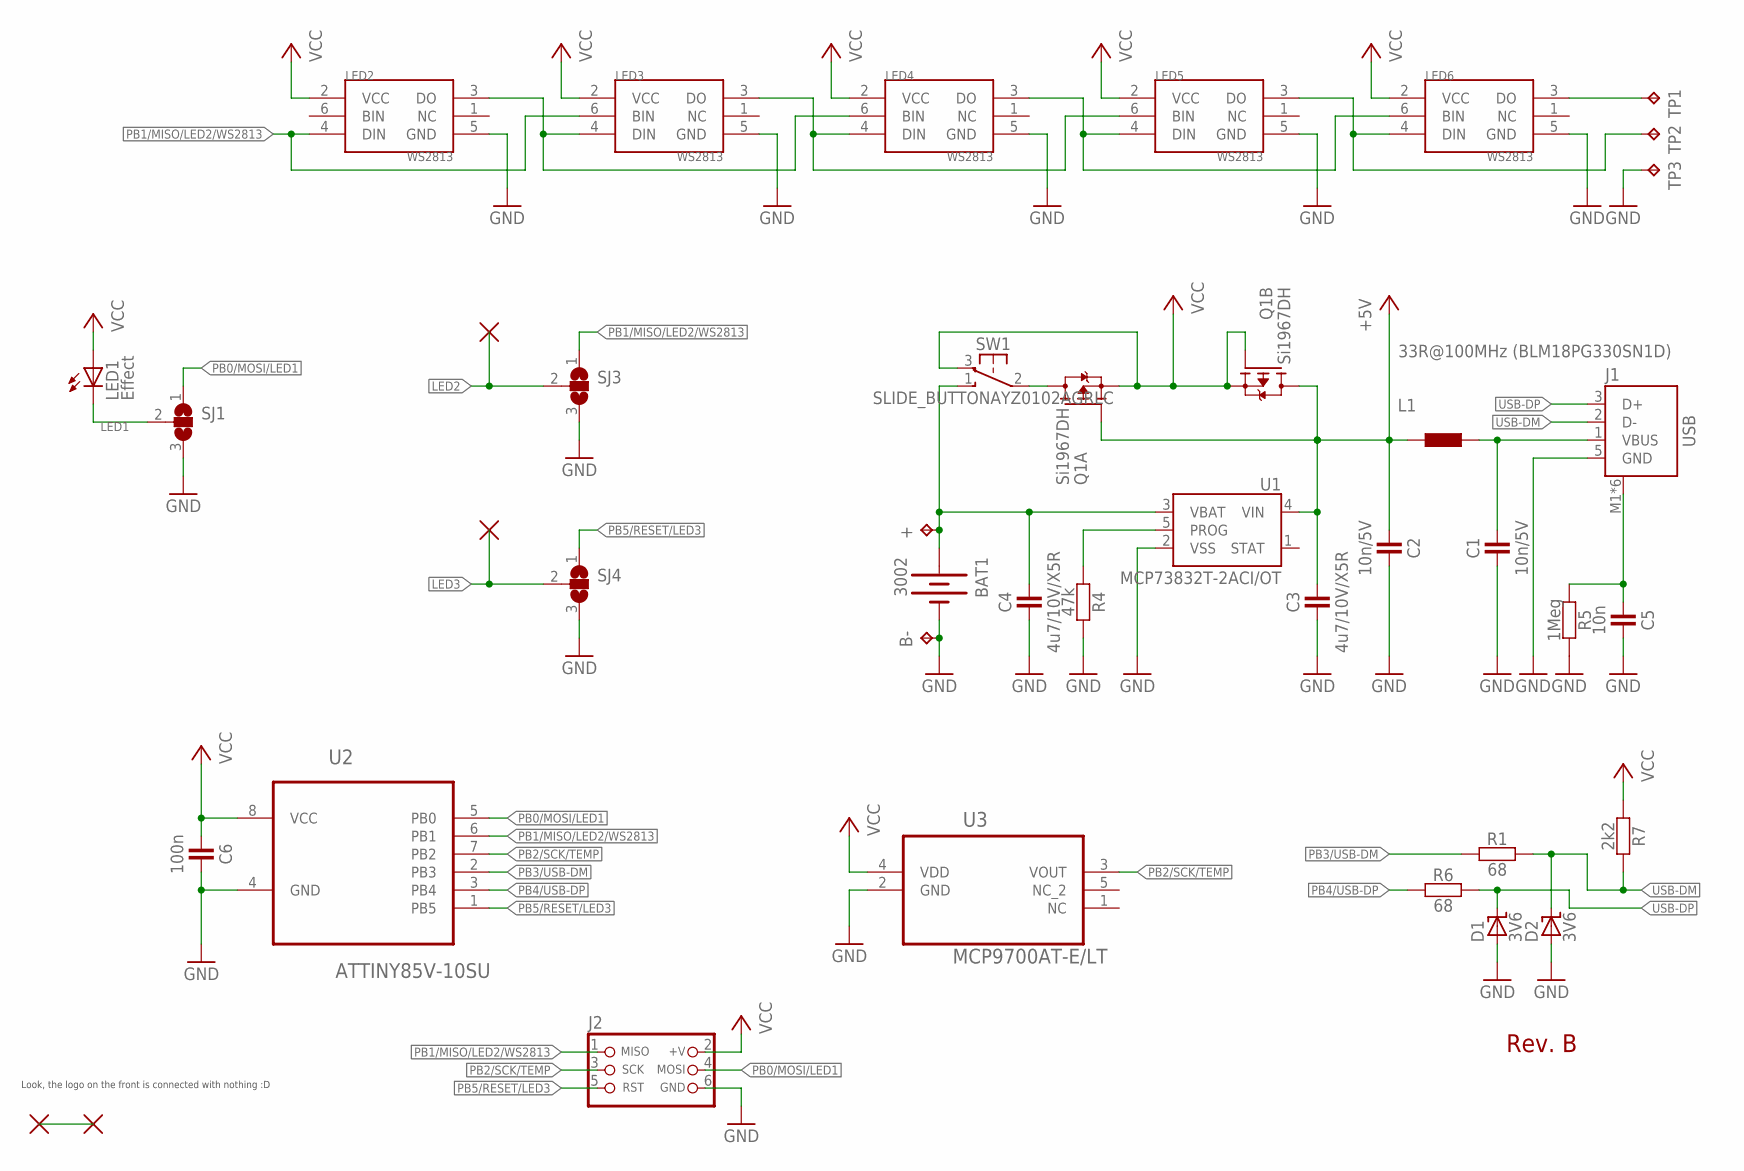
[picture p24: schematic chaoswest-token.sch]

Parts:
+: TPTP18SQ; TP18SQ
B-: TPTP18SQ; TP18SQ
BAT1: 3002; BATTCON_20MM
C1, C2: 10n/5V; C0805
C3, C4: 4u7/10V/X5R; C0805
C5: 10n; C0805
C6: 100n; C0805
D1, D2: 3V6; SOD123
J1: USB; MOLEX_47346-0001
J2: ISP; M2X3_SMD
L1: 33R@100MHz (BLM18PG330SN1D); C0805
LED1: Effect; LED5MM
LED2, LED3, LED4, LED5, LED6: WS2813
Q1: Si1967DH; SOT363
R1, R6: 68; C0805
R4: 47k; C0805
R5: 1Meg; C0805
R7: 2k2; C0805
SJ1, SJ3, SJ4: SJ2W; SJ_2
SW1: SLIDE_BUTTONAYZ0102AGRLC; AYZ0102AGRLC
TP1: DO; TP09SQ
TP2: BO; TP09SQ
TP3: GND; TP09SQ
U1: MCP73832T-2ACI/OT; SOT23-5
U2: ATTINY85V-10SU; SOIC127P798X216-8N
U3: MCP9700AT-E/LT; SOT65P210X110-5N
U$1, U$2, U$3, U$4: EMPTY_SIGNAL; SMALLSPOT

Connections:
+5V: C2.1, C3.1, L1.2, Q1.2 (G), Q1.3 (D), U1.4 (VIN)
GND: B-.TP, BAT1.-, C1.2, C2.2, C3.2, C4.2, C5.2, C6.2, D1.A, D2.A, J1.5 (GND), J2.6 (GND), LED2.5 (GND), LED3.5 (GND), LED4.5 (GND), LED5.5 (GND), LED6.5 (GND), R4.1, R5.1, SJ1.3, SJ3.3, SJ4.3, TP3.TP, U1.2 (VSS), U2.4 (GND), U3.2 (GND)
LED1: LED1.K (C), SJ1.2
LED2: SJ3.2, U$3.X
LED3: SJ4.2, U$4.X
unnamed: LED2.3 (DO), LED3.4 (DIN), LED4.6 (BIN)
unnamed: Q1.6 (D), SW1.2 (P1)
unnamed: LED3.3 (DO), LED4.4 (DIN), LED5.6 (BIN)
unnamed: U$1.X, U$2.X
unnamed: R4.2, U1.5 (PROG)
unnamed: LED4.3 (DO), LED5.4 (DIN), LED6.6 (BIN)
unnamed: LED5.3 (DO), LED6.4 (DIN), TP2.TP
unnamed: LED6.3 (DO), TP1.TP
unnamed: C5.1, J1.M1 (SHIELD), J1.M2 (SHIELD), J1.M3 (SHIELD), J1.M4 (SHIELD), J1.M5 (SHIELD), J1.M6 (SHIELD), R5.2
PB0/MOSI/LED1: J2.4 (MOSI), SJ1.1, U2.5 (PB0)
PB1/MISO/LED2/WS2813: J2.1 (MISO), LED2.4 (DIN), LED3.6 (BIN), SJ3.1, U2.6 (PB1)
PB2/SCK/TEMP: J2.3 (SCK), U2.7 (PB2), U3.3 (VOUT)
PB3/USB-DM: R1.2, U2.2 (PB3)
PB4/USB-DP: R6.2, U2.3 (PB4)
PB5/RESET/LED3: J2.5 (RST), SJ4.1, U2.1 (PB5)
USB-DM: D2.C, J1.2 (D-), R1.1, R7.1
USB-DP: D1.C, J1.3 (D+), R6.1
VBAT: +.TP, BAT1.+1 (+), BAT1.+2 (+), C4.1, SW1.1 (S1), U1.3 (VBAT)
VBUS: C1.1, J1.1 (VBUS), L1.1
VCC: C6.1, J2.2 (+V), LED1.A, LED2.2 (VCC), LED3.2 (VCC), LED4.2 (VCC), LED5.2 (VCC), LED6.2 (VCC), Q1.1 (S), Q1.4 (S), Q1.5 (G), R7.2, SW1.3 (O1), U2.8 (VCC), U3.4 (VDD)

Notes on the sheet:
Look, the logo on the front is connected with nothing :D
Rev. B

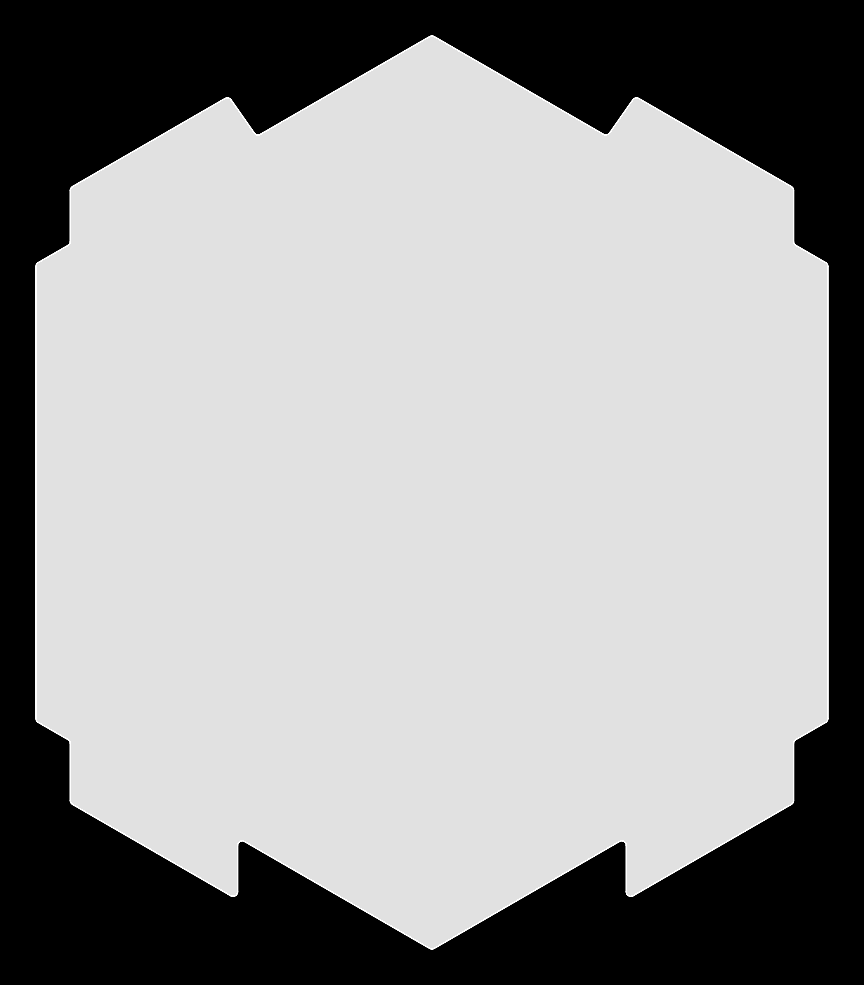
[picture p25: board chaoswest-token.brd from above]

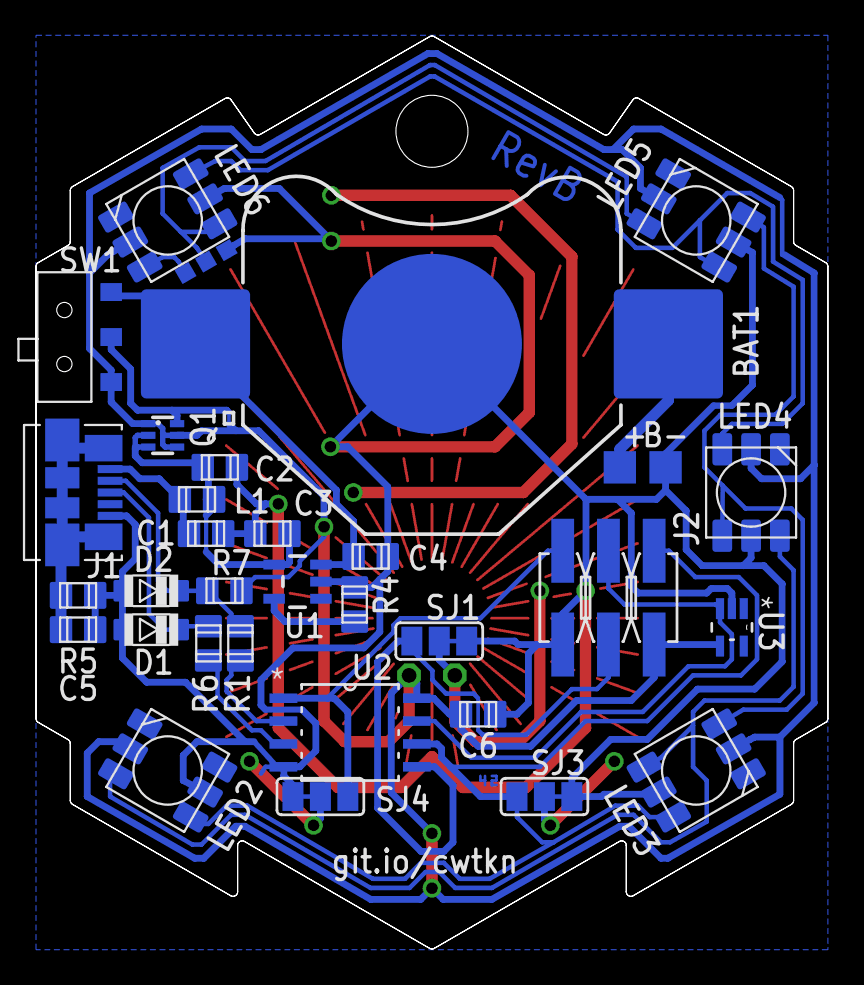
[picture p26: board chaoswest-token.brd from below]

Board: 2 copper layers, 44.0 x 50.7 mm, 40 parts (35 on the bottom side), 25 nets.

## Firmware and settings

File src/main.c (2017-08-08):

#include <avr/io.h>
#include <avr/interrupt.h>
#include <avr/pgmspace.h>
#include <avr/eeprom.h>
#include <util/delay.h>

#include "temperature.h"
#include "i2cusb.h"
#include "light_ws2812.h"

#define LED_R (1 << PB5)
#define LED_G (1 << PB0)
#define LED_B (1 << PB1)

#define NUM_LEDS 6
struct cRGB leds[NUM_LEDS];
struct cRGB fade[NUM_LEDS];

struct cRGB frame[NUM_LEDS];

uint8_t config_brightness EEMEM = 0x80;
uint8_t config_osccal EEMEM;

uint8_t brightness_cache;
uint8_t pwmClock = 0;
uint8_t animation = 1;

const uint8_t pwmTable[] PROGMEM = {
	0x00, 0x01, 0x01, 0x01, 0x01, 0x01, 0x01, 0x01, 0x01, 0x01, 0x01, 0x01, 0x01, 0x01, 0x01, 0x01,
	0x01, 0x01, 0x02, 0x02, 0x02, 0x02, 0x02, 0x02, 0x02, 0x02, 0x02, 0x02, 0x02, 0x02, 0x02, 0x02,
	0x02, 0x02, 0x02, 0x02, 0x02, 0x02, 0x02, 0x02, 0x02, 0x02, 0x03, 0x03, 0x03, 0x03, 0x03, 0x03,
	0x03, 0x03, 0x03, 0x03, 0x03, 0x03, 0x03, 0x03, 0x03, 0x04, 0x04, 0x04, 0x04, 0x04, 0x04, 0x04,
	0x04, 0x04, 0x04, 0x04, 0x04, 0x05, 0x05, 0x05, 0x05, 0x05, 0x05, 0x05, 0x05, 0x05, 0x06, 0x06,
	0x06, 0x06, 0x06, 0x06, 0x06, 0x06, 0x07, 0x07, 0x07, 0x07, 0x07, 0x07, 0x07, 0x08, 0x08, 0x08,
	0x08, 0x08, 0x09, 0x09, 0x09, 0x09, 0x09, 0x09, 0x0a, 0x0a, 0x0a, 0x0a, 0x0b, 0x0b, 0x0b, 0x0b,
	0x0c, 0x0c, 0x0c, 0x0c, 0x0d, 0x0d, 0x0d, 0x0d, 0x0e, 0x0e, 0x0e, 0x0f, 0x0f, 0x0f, 0x10, 0x10,
	0x10, 0x11, 0x11, 0x11, 0x12, 0x12, 0x13, 0x13, 0x13, 0x14, 0x14, 0x15, 0x15, 0x16, 0x16, 0x17,
	0x17, 0x18, 0x18, 0x19, 0x19, 0x1a, 0x1a, 0x1b, 0x1b, 0x1c, 0x1d, 0x1d, 0x1e, 0x1f, 0x1f, 0x20,
	0x21, 0x21, 0x22, 0x23, 0x24, 0x24, 0x25, 0x26, 0x27, 0x28, 0x29, 0x29, 0x2a, 0x2b, 0x2c, 0x2d,
	0x2e, 0x2f, 0x30, 0x31, 0x32, 0x33, 0x35, 0x36, 0x37, 0x38, 0x39, 0x3b, 0x3c, 0x3d, 0x3e, 0x40,
	0x41, 0x43, 0x44, 0x46, 0x47, 0x49, 0x4a, 0x4c, 0x4e, 0x4f, 0x51, 0x53, 0x55, 0x56, 0x58, 0x5a,
	0x5c, 0x5e, 0x60, 0x62, 0x65, 0x67, 0x69, 0x6b, 0x6e, 0x70, 0x72, 0x75, 0x78, 0x7a, 0x7d, 0x80,
	0x82, 0x85, 0x88, 0x8b, 0x8e, 0x91, 0x94, 0x98, 0x9b, 0x9e, 0xa2, 0xa5, 0xa9, 0xad, 0xb0, 0xb4,
	0xb8, 0xbc, 0xc0, 0xc5, 0xc9, 0xcd, 0xd2, 0xd6, 0xdb, 0xe0, 0xe5, 0xea, 0xef, 0xf4, 0xfa, 0xff
};

uint8_t invalidate_ws2813 = 0;

void updateFrame(uint8_t index, uint8_t channel) {
	uint8_t temp_color = ((uint16_t)((uint8_t*)(leds + index))[channel]) * brightness_cache / 255;
	if (index == 0) {
		temp_color = pgm_read_byte(&(pwmTable[temp_color]));
	}
	((uint8_t*)(frame + index))[channel] = temp_color;
	if (index > 0) {
		invalidate_ws2813 = 1;
	}
}

void setFadeColorValue(uint8_t index, uint8_t channel, uint8_t value) {
	((uint8_t*)(fade + index))[channel] = value;
}

void setColorValue(uint8_t index, uint8_t channel, uint8_t value) {
	((uint8_t*)(leds + index))[channel] = value;
	((uint8_t*)(fade + index))[channel] = value;
	updateFrame(index, channel);
}

uint8_t getColorValue(uint8_t index, uint8_t channel) {
	return ((uint8_t*)(leds + index))[channel];
}

int main(void) {
	// Initialize Temperature Sensor and USB
	usb_setup();
	temperature_setup();

	// Initialize GPIOs
	PORTB |= LED_R | LED_G | LED_B;
	DDRB |= LED_R | LED_G | LED_B;

	// Load the stored LED Brightness
	brightness_cache = eeprom_read_byte(&config_brightness);

	// Set the back WS2813 LEDs
	leds[1].r=255;leds[1].g=0;leds[1].b=0;
	leds[2].r=255;leds[2].g=255;leds[2].b=0;	
	leds[3].r=0;leds[3].g=255;leds[3].b=0;
	leds[4].r=0;leds[4].g=0;leds[4].b=255;
	leds[5].r=255;leds[5].g=0;leds[5].b=255;
	for(uint8_t i = 0; i < NUM_LEDS; i++) {
		for(uint8_t j = 0; j < 3; j++) {
			updateFrame(i, j);
		}
	}

    uint16_t virtual_timer = 0;
    uint8_t step = 0;
    for(;;)
	{
		// Update WS2813
		/*if (invalidate_ws2813 == 1) {
			invalidate_ws2813 = 0;
			PORTB &= ~LED_B;
			_delay_ms(100);
			ws2812_setleds(frame+1,5);
			_delay_ms(100);
			PORTB |= LED_B;
		}*/

		virtual_timer++;
		if (virtual_timer == 0) {
			temperature_measure(); // Start Temperature Measurement

			// Front LED Animation
			if (animation) {
				switch (step) {
					case 0:
					setFadeColorValue(0, 0, 255);
					setFadeColorValue(0, 1, 0);
					setFadeColorValue(0, 2, 0);
					break;

					case 1:
					setFadeColorValue(0, 0, 255);
					setFadeColorValue(0, 1, 255);
					setFadeColorValue(0, 2, 0);
					break;

					case 2:
					setFadeColorValue(0, 0, 0);
					setFadeColorValue(0, 1, 255);
					setFadeColorValue(0, 2, 0);
					break;

					case 3:
					setFadeColorValue(0, 0, 0);
					setFadeColorValue(0, 1, 255);
					setFadeColorValue(0, 2, 255);
					break;

					case 4:
					setFadeColorValue(0, 0, 0);
					setFadeColorValue(0, 1, 0);
					setFadeColorValue(0, 2, 255);
					break;

					case 5:
					setFadeColorValue(0, 0, 255);
					setFadeColorValue(0, 1, 0);
					setFadeColorValue(0, 2, 255);
					step = -1;
					break;

					default:
					break;
				}
				step++;
			}
		}
		
		// Software PWM of Front LED
		if (pwmClock < frame[0].r) {
			PORTB &= ~LED_R;
		} else {
			PORTB |= LED_R;
		}
		if (pwmClock < frame[0].g) {
			PORTB &= ~LED_G;
		} else {
			PORTB |= LED_G;
		}
		if (pwmClock < frame[0].b) {
			PORTB &= ~LED_B;
		} else {
			PORTB |= LED_B;
		}

		pwmClock++;

		// Calculate next Color
		if (pwmClock == 0) {
			for (uint8_t j = 0; j < NUM_LEDS; j++) {
				for (uint8_t i = 0; i < 3; i++) {
					if (((uint8_t*)(leds + j))[i] > ((uint8_t*)(fade + j))[i]) {
						((uint8_t*)(leds + j))[i]--;
						updateFrame(j, i);
					} else if (((uint8_t*)leds + j)[i] < ((uint8_t*)(fade + j))[i]) {
						((uint8_t*)(leds + j))[i]++;
						updateFrame(j, i);
					}
				}
			}
		}

		// USB Loop
		usb_loop();
	}

    return 0; 
}

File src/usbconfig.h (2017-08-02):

/* Name: usbconfig.h
 * Project: AVR USB driver
 * Author: Christian Starkjohann
 * Creation Date: 2007-06-23
 * Tabsize: 4
 * Copyright: (c) 2007 by OBJECTIVE DEVELOPMENT Software GmbH
 * License: GNU GPL v2 (see License.txt) or proprietary (CommercialLicense.txt)
 * This Revision: $Id: usbconfig.h 537 2008-02-28 21:13:01Z cs $
 */

#ifndef __usbconfig_h_included__
#define __usbconfig_h_included__

/* ---------------------------- Hardware Config ---------------------------- */

#define USB_CFG_IOPORTNAME      B
/* This is the port where the USB bus is connected. When you configure it to
 * "B", the registers PORTB, PINB and DDRB will be used.
 */
#define USB_CFG_DMINUS_BIT      3
/* This is the bit number in USB_CFG_IOPORT where the USB D- line is connected.
 * This may be any bit in the port.
 */
#define USB_CFG_DPLUS_BIT       4
/* This is the bit number in USB_CFG_IOPORT where the USB D+ line is connected.
 * This may be any bit in the port. Please note that D+ must also be connected
 * to interrupt pin INT0!
 */
#define USB_CFG_CLOCK_KHZ       (F_CPU/1000)
/* Clock rate of the AVR in MHz. Legal values are 12000, 16000 or 16500.
 * The 16.5 MHz version of the code requires no crystal, it tolerates +/- 1%
 * deviation from the nominal frequency. All other rates require a precision
 * of 2000 ppm and thus a crystal!
 * Default if not specified: 12 MHz
 */

/* ----------------------- Optional Hardware Config ------------------------ */

/* #define USB_CFG_PULLUP_IOPORTNAME   D */
/* If you connect the 1.5k pullup resistor from D- to a port pin instead of
 * V+, you can connect and disconnect the device from firmware by calling
 * the macros usbDeviceConnect() and usbDeviceDisconnect() (see usbdrv.h).
 * This constant defines the port on which the pullup resistor is connected.
 */
/* #define USB_CFG_PULLUP_BIT          4 */
/* This constant defines the bit number in USB_CFG_PULLUP_IOPORT (defined
 * above) where the 1.5k pullup resistor is connected. See description
 * above for details.
 */

/* --------------------------- Functional Range ---------------------------- */

#define USB_CFG_HAVE_INTRIN_ENDPOINT    0
/* Define this to 1 if you want to compile a version with two endpoints: The
 * default control endpoint 0 and an interrupt-in endpoint 1.
 */
#define USB_CFG_HAVE_INTRIN_ENDPOINT3   0
/* Define this to 1 if you want to compile a version with three endpoints: The
 * default control endpoint 0, an interrupt-in endpoint 1 and an interrupt-in
 * endpoint 3. You must also enable endpoint 1 above.
 */
#define USB_CFG_IMPLEMENT_HALT          0
/* Define this to 1 if you also want to implement the ENDPOINT_HALT feature
 * for endpoint 1 (interrupt endpoint). Although you may not need this feature,
 * it is required by the standard. We have made it a config option because it
 * bloats the code considerably.
 */
#define USB_CFG_INTR_POLL_INTERVAL      10
/* If you compile a version with endpoint 1 (interrupt-in), this is the poll
 * interval. The value is in milliseconds and must not be less than 10 ms for
 * low speed devices.
 */
#define USB_CFG_IS_SELF_POWERED         0
/* Define this to 1 if the device has its own power supply. Set it to 0 if the
 * device is powered from the USB bus.
 */
#define USB_CFG_MAX_BUS_POWER           200
/* Set this variable to the maximum USB bus power consumption of your device.
 * The value is in milliamperes. [It will be divided by two since USB
 * communicates power requirements in units of 2 mA.]
 */
#define USB_CFG_IMPLEMENT_FN_WRITE      1
/* Set this to 1 if you want usbFunctionWrite() to be called for control-out
 * transfers. Set it to 0 if you don't need it and want to save a couple of
 * bytes.
 */
#define USB_CFG_IMPLEMENT_FN_READ       1
/* Set this to 1 if you need to send control replies which are generated
 * "on the fly" when usbFunctionRead() is called. If you only want to send
 * data from a static buffer, set it to 0 and return the data from
 * usbFunctionSetup(). This saves a couple of bytes.
 */
#define USB_CFG_IMPLEMENT_FN_WRITEOUT   0
/* Define this to 1 if you want to use interrupt-out (or bulk out) endpoint 1.
 * You must implement the function usbFunctionWriteOut() which receives all
 * interrupt/bulk data sent to endpoint 1.
 */
#define USB_CFG_HAVE_FLOWCONTROL        0
/* Define this to 1 if you want flowcontrol over USB data. See the definition
 * of the macros usbDisableAllRequests() and usbEnableAllRequests() in
 * usbdrv.h.
 */
#ifndef __ASSEMBLER__
extern void usbEventResetReady(void);
#endif
#define USB_RESET_HOOK(isReset)             if(!isReset){usbEventResetReady();}
/* This macro is a hook if you need to know when an USB RESET occurs. It has
 * one parameter which distinguishes between the start of RESET state and its
 * end.
 */
#define USB_CFG_HAVE_MEASURE_FRAME_LENGTH   1
/* define this macro to 1 if you want the function usbMeasureFrameLength()
 * compiled in. This function can be used to calibrate the AVR's RC oscillator.
 */
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

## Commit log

2017-06-23 initial commit, adding current eagle state and also the design track and some readme
    [chaoswest-logo-milling.dxf, chaoswest-logo_8.ipt, chaoswest-logo_copper_beams.dxf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]
2017-06-24 current status of board (front side quasi final) and some more dxf / xml files added
    [chaoswest-logo_stop_text2.dxf, chaoswest-token.brd, chaoswest-token.sch]
2017-06-24 current front view from eagle added
2017-06-24 current inventor file added
    [chaoswest-logo_9.ipt]
2017-06-25 schematic should be mostly done, routing is in process, 42 airwires left
    [chaoswest-token.brd, chaoswest-token.sch]
2017-06-26 routing finished, single layer layout
    [chaoswest-token.brd, chaoswest-token.sch]
2017-06-26 schematic added as PDF
2017-06-26 minor change at the default jumper settings of the switch
    [chaoswest-token.brd]
2017-06-26 put the bottom silk screen (component names) into place
    [chaoswest-token.brd, chaoswest-token.sch]
2017-06-28 current (hopefully nearly final) state of the PCB, minor changes, gerber files produced
    [chaoswest-token.brd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]
2017-06-28 outlines added to gerbers
    [chaoswest-token.gbl, chaoswest-token.gbs, chaoswest-token.gko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]
2017-07-26 documentation updated to the current state
2017-08-08 current firmware status, WS2813 for some reason non working
2017-08-08 sha documentation prints added
2018-10-31 pcb revision b added for new production cycle
    [chaoswest-token.brd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]
2018-11-14 Rev B Hardware completed and ordered
    [chaoswest-token.brd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]

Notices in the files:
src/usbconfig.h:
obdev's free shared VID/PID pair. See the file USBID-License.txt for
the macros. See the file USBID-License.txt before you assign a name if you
